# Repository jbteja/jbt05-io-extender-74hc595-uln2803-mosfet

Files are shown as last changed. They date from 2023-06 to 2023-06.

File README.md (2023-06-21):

# IO extender for switching low-current motors and solenoid valves
> Image of the board:
<p align="center">
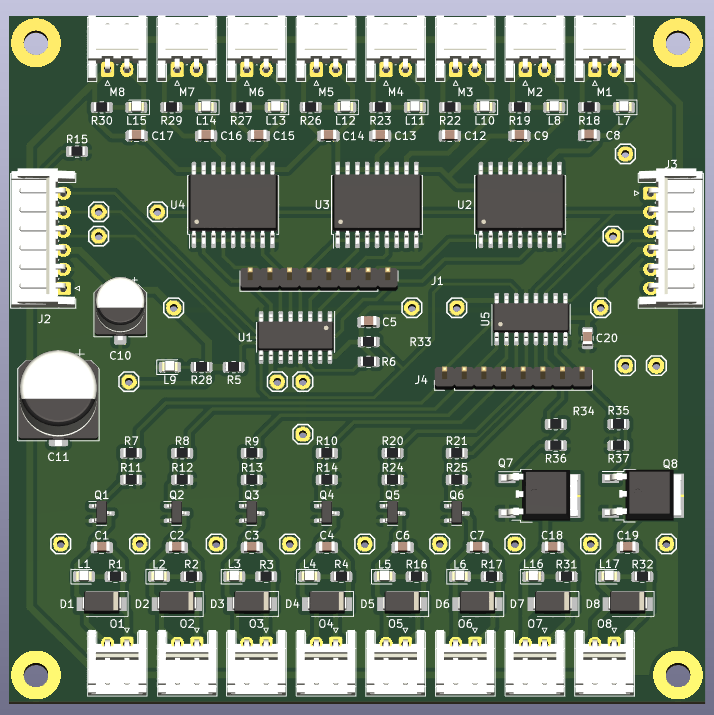
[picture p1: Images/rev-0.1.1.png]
  
</p>

> 3D view of the board:
<figure class="video_container">
  <video controls="true" allowfullscreen="true">
    <source src="3D/rev-0.1.1.mp4" type="video/mp4">
  </video>
</figure>

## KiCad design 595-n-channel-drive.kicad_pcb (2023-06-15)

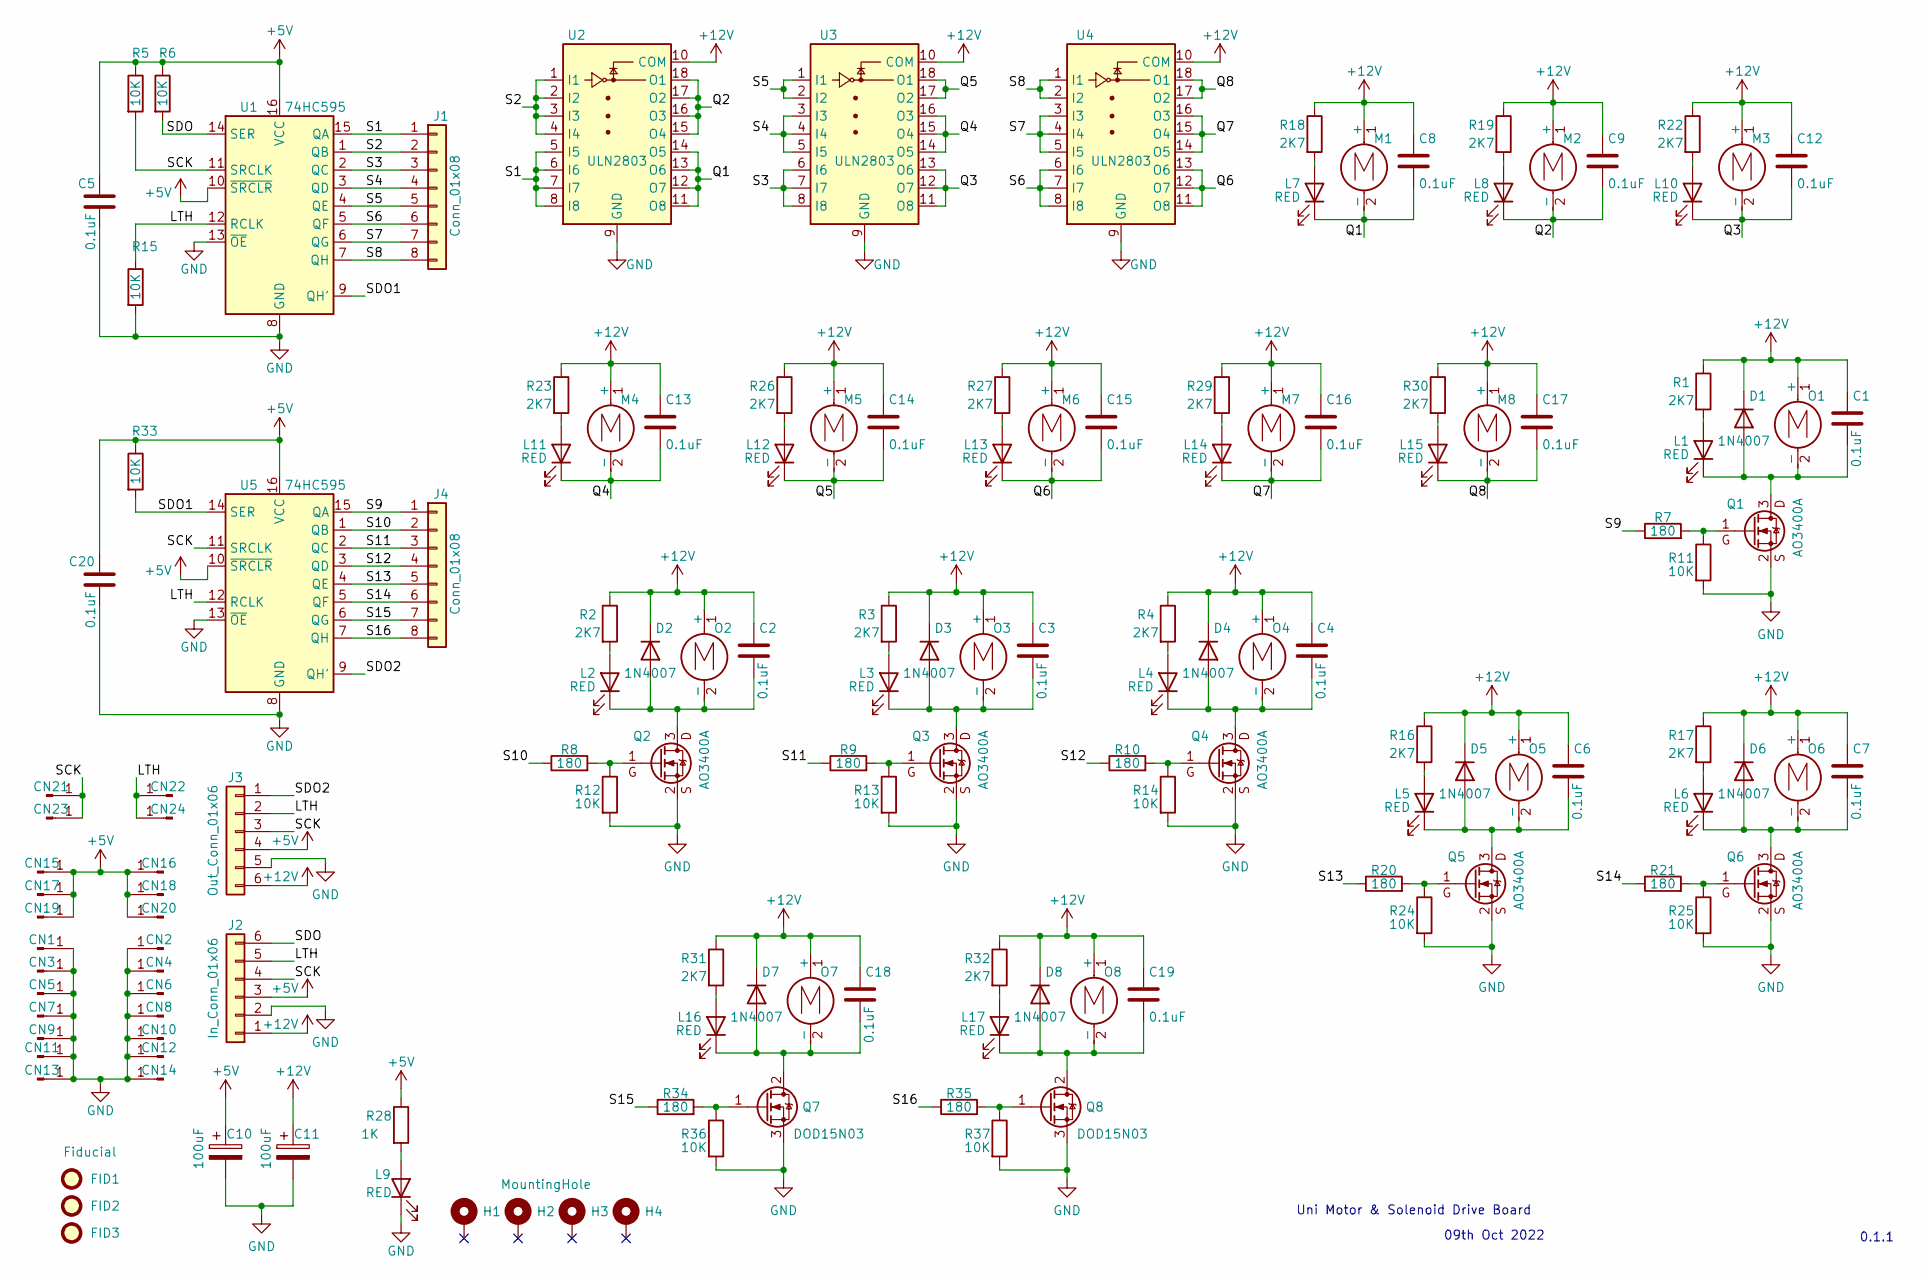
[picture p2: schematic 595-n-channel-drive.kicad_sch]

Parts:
C1, C2, C3, C4, C5, C6, C7, C8, C9, C12, C13, C14, C15, C16, C17, C18, C19, C20: 0.1uF; C_0805_2012Metric
C10: 100uF; CP_Elec_6.3x7.7
C11: 100uF; CP_Elec_10x10
CN1, CN2, CN3, CN4, CN5, CN6, CN7, CN8, CN9, CN10, CN11, CN12, CN13, CN14, CN15, CN16, CN17, CN18, CN19, CN20, CN21, CN22, CN23, CN24: Conn_01x01_Male; 1X01
D1, D2, D3, D4, D5, D6, D7, D8: 1N4007; D_SMA
FID1, FID2, FID3: Fiducial; Fiducial_0.5mm_Mask1mm
H1, H2, H3, H4: MountingHole; MountingHole_3.2mm_M3_Pad
J1, J4: Conn_01x08; PinHeader_1x08_P2.54mm_Vertical
J2: In_Conn_01x06; JST_EH_S6B-EH_1x06_P2.50mm_Horizontal
J3: Out_Conn_01x06; JST_EH_S6B-EH_1x06_P2.50mm_Horizontal
L1, L2, L3, L4, L5, L6, L7, L8, L9, L10, L11, L12, L13, L14, L15, L16, L17: RED; LED_0805_2012Metric
M1, M2, M3, M4, M5, M6, M7, M8: Motor_DC; JST_EH_S2B-EH_1x02_P2.50mm_Horizontal
O1, O2, O3, O4, O5, O6, O7, O8: Motor_DC; JST_EH_S2B-EH_1x02_P2.50mm_Horizontal
Q1, Q2, Q3, Q4, Q5, Q6: AO3400A; SOT-23
Q7, Q8: DOD15N03; TO-252-2
R1, R2, R3, R4, R16, R17, R18, R19, R22, R23, R26, R27, R29, R30, R31, R32: 2K7; R_0805_2012Metric
R5, R6, R11, R12, R13, R14, R15, R24, R25, R33, R36, R37: 10K; R_0805_2012Metric
R7, R8, R9, R10, R20, R21, R34, R35: 180; R_0805_2012Metric
R28: 1K; R_0805_2012Metric
U1, U5: 74HC595; SOIC-16_3.9x9.9mm_P1.27mm
U2, U3, U4: ULN2803; SOIC-18W_7.5x11.6mm_P1.27mm

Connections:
+5V: C5.1, C10.1, C20.1, CN15.1, CN16.1, CN17.1, CN18.1, CN19.1, CN20.1, J2.3, J3.4, R5.1, R6.1, R28.1, R33.1, U1.10 (~SRCLR), U1.16 (VCC), U5.10 (~SRCLR), U5.16 (VCC)
+12V: C1.1, C2.1, C3.1, C4.1, C6.1, C7.1, C8.1, C9.1, C11.1, C12.1, C13.1, C14.1, C15.1, C16.1, C17.1, C18.1, C19.1, D1.1 (K), D2.1 (K), D3.1 (K), D4.1 (K), D5.1 (K), D6.1 (K), D7.1 (K), D8.1 (K), J2.1, J3.6, M1.1 (+), M2.1 (+), M3.1 (+), M4.1 (+), M5.1 (+), M6.1 (+), M7.1 (+), M8.1 (+), O1.1 (+), O2.1 (+), O3.1 (+), O4.1 (+), O5.1 (+), O6.1 (+), O7.1 (+), O8.1 (+), R1.1, R2.1, R3.1, R4.1, R16.1, R17.1, R18.1, R19.1, R22.1, R23.1, R26.1, R27.1, R29.1, R30.1, R31.1, R32.1, U2.10 (COM), U3.10 (COM), U4.10 (COM)
/LTH: CN22.1, CN24.1, J2.5, J3.2, R15.1, U1.12 (RCLK), U5.12 (RCLK)
/Q1: C8.2, L7.1 (K), M1.2 (-), U2.11 (O8), U2.12 (O7), U2.13 (O6), U2.14 (O5)
/Q2: C9.2, L8.1 (K), M2.2 (-), U2.15 (O4), U2.16 (O3), U2.17 (O2), U2.18 (O1)
/Q3: C12.2, L10.1 (K), M3.2 (-), U3.11 (O8), U3.12 (O7), U3.13 (O6)
/Q4: C13.2, L11.1 (K), M4.2 (-), U3.14 (O5), U3.15 (O4), U3.16 (O3)
/Q5: C14.2, L12.1 (K), M5.2 (-), U3.17 (O2), U3.18 (O1)
/Q6: C15.2, L13.1 (K), M6.2 (-), U4.11 (O8), U4.12 (O7), U4.13 (O6)
/Q7: C16.2, L14.1 (K), M7.2 (-), U4.14 (O5), U4.15 (O4), U4.16 (O3)
/Q8: C17.2, L15.1 (K), M8.2 (-), U4.17 (O2), U4.18 (O1)
/S1: J1.1, U1.15 (QA), U2.5 (I5), U2.6 (I6), U2.7 (I7), U2.8 (I8)
/S2: J1.2, U1.1 (QB), U2.1 (I1), U2.2 (I2), U2.3 (I3), U2.4 (I4)
/S3: J1.3, U1.2 (QC), U3.6 (I6), U3.7 (I7), U3.8 (I8)
/S4: J1.4, U1.3 (QD), U3.3 (I3), U3.4 (I4), U3.5 (I5)
/S5: J1.5, U1.4 (QE), U3.1 (I1), U3.2 (I2)
/S6: J1.6, U1.5 (QF), U4.6 (I6), U4.7 (I7), U4.8 (I8)
/S7: J1.7, U1.6 (QG), U4.3 (I3), U4.4 (I4), U4.5 (I5)
/S8: J1.8, U1.7 (QH), U4.1 (I1), U4.2 (I2)
/S9: J4.1, R7.1, U5.15 (QA)
/S10: J4.2, R8.1, U5.1 (QB)
/S11: J4.3, R9.1, U5.2 (QC)
/S12: J4.4, R10.1, U5.3 (QD)
/S13: J4.5, R20.1, U5.4 (QE)
/S14: J4.6, R21.1, U5.5 (QF)
/S15: J4.7, R34.1, U5.6 (QG)
/S16: J4.8, R35.1, U5.7 (QH)
/SCK: CN21.1, CN23.1, J2.4, J3.3, R5.2, U1.11 (SRCLK), U5.11 (SRCLK)
/SDO: J2.6, R6.2, U1.14 (SER)
/SDO1: R33.2, U1.9 (QH'), U5.14 (SER)
/SDO2: J3.1, U5.9 (QH')
GND: C5.2, C10.2, C11.2, C20.2, CN1.1, CN2.1, CN3.1, CN4.1, CN5.1, CN6.1, CN7.1, CN8.1, CN9.1, CN10.1, CN11.1, CN12.1, CN13.1, CN14.1, J2.2, J3.5, L9.1 (K), Q1.2 (S), Q2.2 (S), Q3.2 (S), Q4.2 (S), Q5.2 (S), Q6.2 (S), Q7.3 (S), Q8.3 (S), R11.2, R12.2, R13.2, R14.2, R15.2, R24.2, R25.2, R36.2, R37.2, U1.8 (GND), U1.13 (~OE), U2.9 (GND), U3.9 (GND), U4.9 (GND), U5.8 (GND), U5.13 (~OE)
unnamed: C1.2, D1.2 (A), L1.1 (K), O1.2 (-), Q1.3 (D)
unnamed: C2.2, D2.2 (A), L2.1 (K), O2.2 (-), Q2.3 (D)
unnamed: C3.2, D3.2 (A), L3.1 (K), O3.2 (-), Q3.3 (D)
unnamed: C4.2, D4.2 (A), L4.1 (K), O4.2 (-), Q4.3 (D)
unnamed: C6.2, D5.2 (A), L5.1 (K), O5.2 (-), Q5.3 (D)
unnamed: C7.2, D6.2 (A), L6.1 (K), O6.2 (-), Q6.3 (D)
unnamed: C18.2, D7.2 (A), L16.1 (K), O7.2 (-), Q7.2 (D)
unnamed: C19.2, D8.2 (A), L17.1 (K), O8.2 (-), Q8.2 (D)
unnamed: L1.2 (A), R1.2
unnamed: L2.2 (A), R2.2
unnamed: L3.2 (A), R3.2
unnamed: L4.2 (A), R4.2
unnamed: L5.2 (A), R16.2
unnamed: L6.2 (A), R17.2
unnamed: L7.2 (A), R18.2
unnamed: L8.2 (A), R19.2
unnamed: L9.2 (A), R28.2
unnamed: L10.2 (A), R22.2
unnamed: L11.2 (A), R23.2
unnamed: L12.2 (A), R26.2
unnamed: L13.2 (A), R27.2
unnamed: L14.2 (A), R29.2
unnamed: L15.2 (A), R30.2
unnamed: L16.2 (A), R31.2
unnamed: L17.2 (A), R32.2
unnamed: Q1.1 (G), R7.2, R11.1
unnamed: Q2.1 (G), R8.2, R12.1
unnamed: Q3.1 (G), R9.2, R13.1
unnamed: Q4.1 (G), R10.2, R14.1
unnamed: Q5.1 (G), R20.2, R24.1
unnamed: Q6.1 (G), R21.2, R25.1
unnamed: Q7.1 (G), R34.2, R36.1
unnamed: Q8.1 (G), R35.2, R37.1

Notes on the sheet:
0.1.1
09th Oct 2022
Uni Motor & Solenoid Drive Board

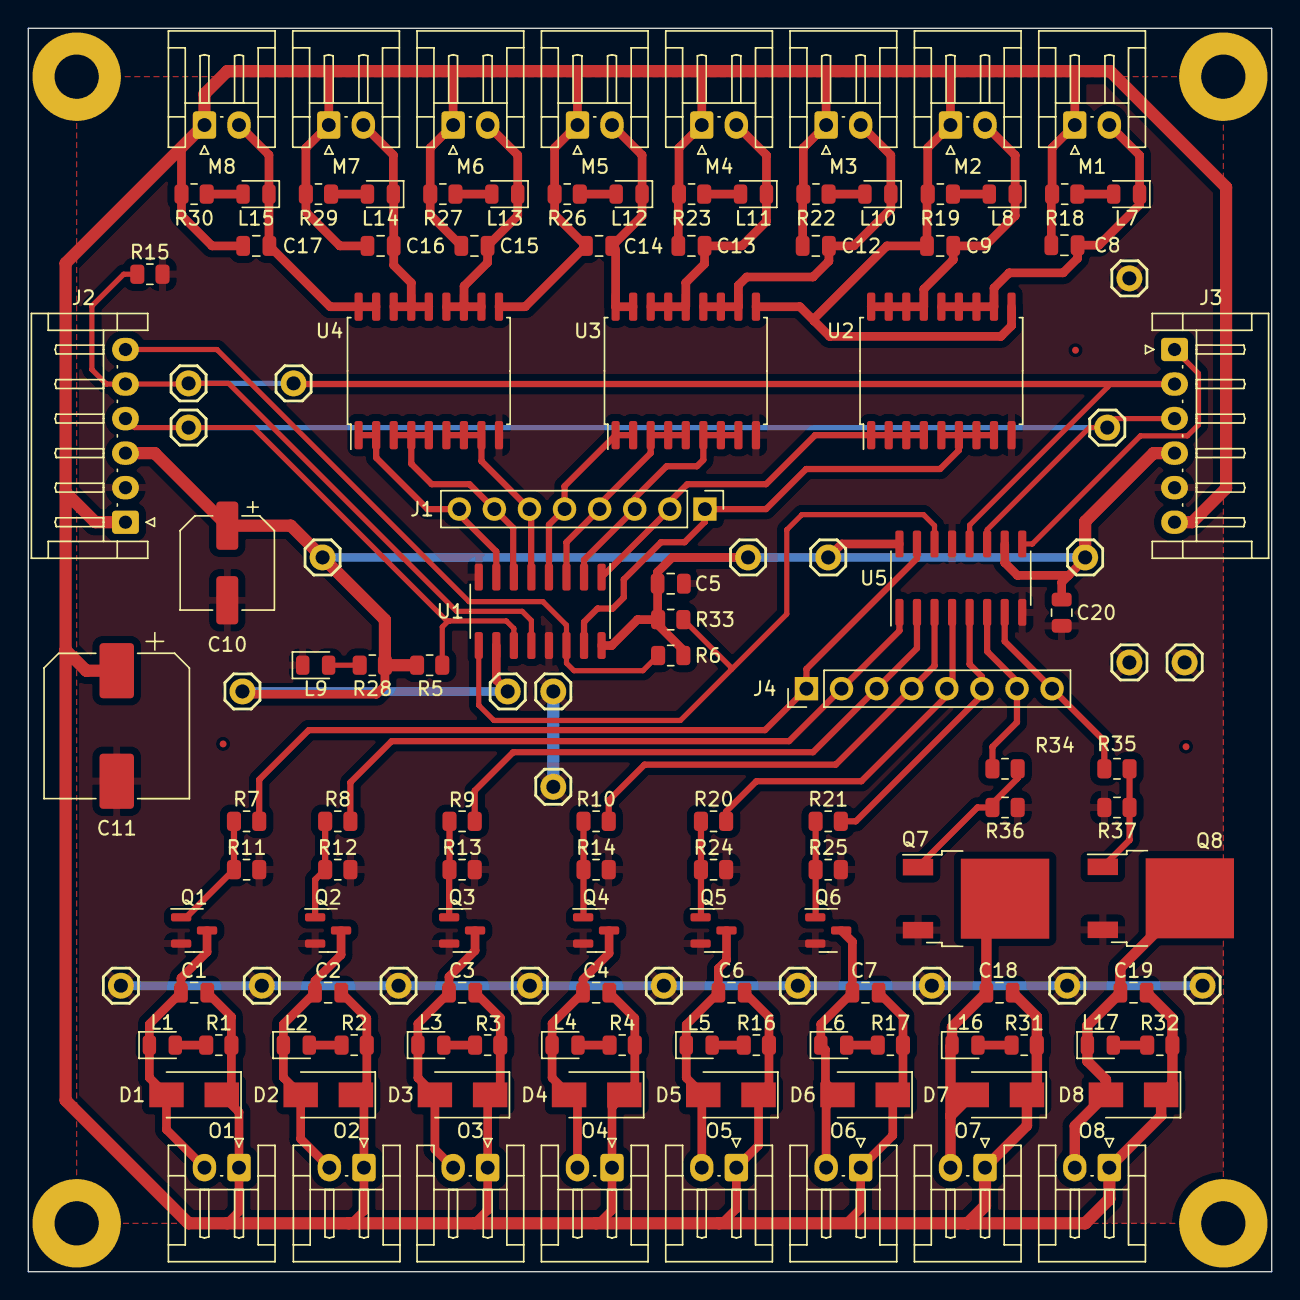
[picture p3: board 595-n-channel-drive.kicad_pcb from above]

Board: 2 copper layers, 90.0 x 90.0 mm, 146 parts (0 on the bottom side), 65 nets.

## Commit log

2023-06-15 Initial commit, Pushing all the staged changes
    [595-n-channel-drive.kicad_pcb, 595-n-channel-drive.kicad_sch]
2023-06-21 Adding 3D view of the board
